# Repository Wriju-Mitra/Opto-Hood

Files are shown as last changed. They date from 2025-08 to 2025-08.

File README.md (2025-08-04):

# Opto-Hood
Low cost system for optogenetically manipulating neurons while simultaneously recording sleep/activity in Drosophila Activity Monitors.
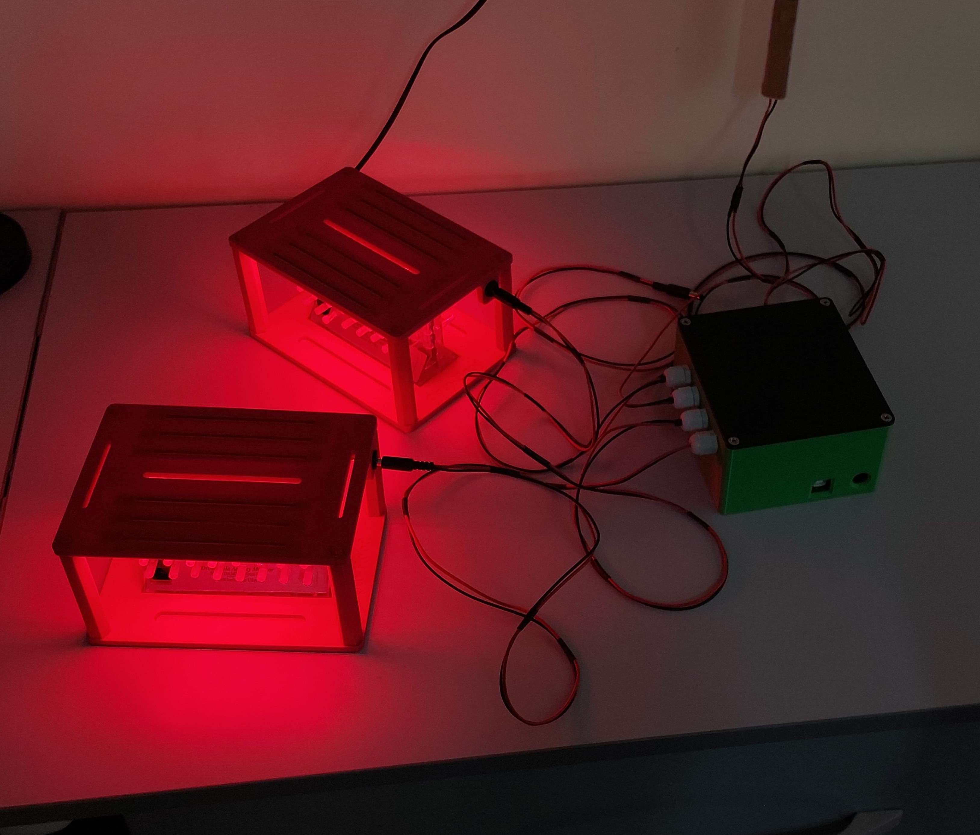
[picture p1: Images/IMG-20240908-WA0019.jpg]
Opto Hood


## Description
The Opto-Hood is a system that allows optogenetic activation(or silencing) of neurons in fruit flies housed in Drosophila Activity Monitors(DAMs). At its heart is an Arduino Uno that controls the duration and frequency of the LEDs that are place over the DAM monitors(like a hood).The system is low cost, and can be built using off-the-shelf electronics. User inputs are acquired through the Arduino IDE hence does not require sophisticated software. Up to four DAMs can be controlled independently by one device.

Detailed info can be found on my [Hackaday page](https://hackaday.io/project/197842-opto-hood)

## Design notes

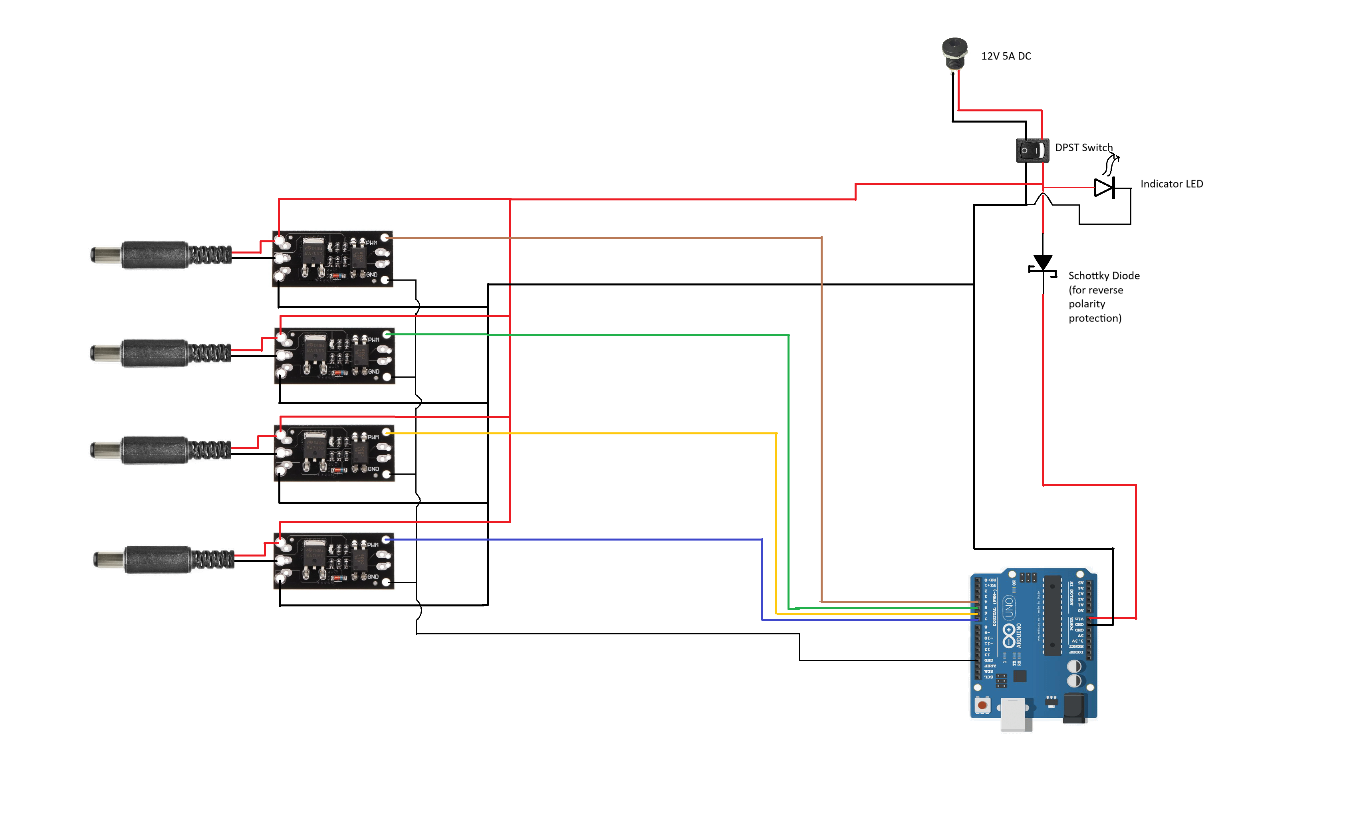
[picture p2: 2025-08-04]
Schematic.png

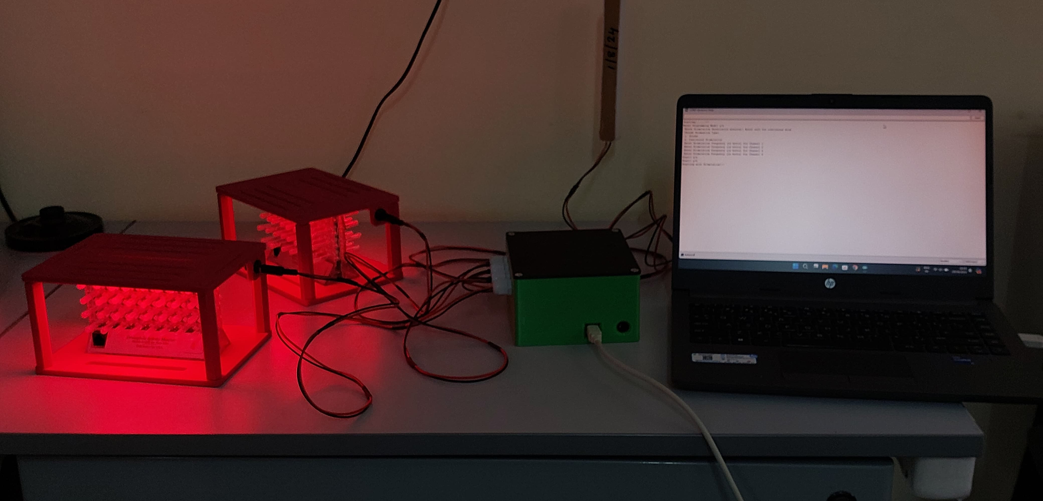
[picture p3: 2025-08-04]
Images/IMG-20240908-WA0015.jpg

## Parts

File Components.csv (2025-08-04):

# | Component Name | No. of units | Comments
1 | Arduino Uno r3 | 1
2 | D4184 Mosfet module | 4
3 | 12V 240 LEDs/meter Red LED strip | 1 | It is preferable to get the 5m strip. Make sure that the LED emits at around 640nm (doesn&apos;t have to be exact, a margin of 30nm on either side is okay)
4 | PG7 cable gland | 4
5 | Barrell Jack 2.2x5.5 Female | 5 | The round type with threads on the outside
6 | Barrell Jack 2.2x5.5 male | 4
7 | 12V 5A power supply | 1
8 | DPST rocker switch | 1
9 | Countersunk Philips Head M3 X 10 mm Bolt | 4
10 | Countersunk Philips Head M3 X 15 mm Bolt | 4
11 | M3 nut | 4
12 | M3 X 6 mm Brass Heat Set Threaded Round Insert | 4
13 | 18AWG insulated wire | 1 | n red and black(10m each) to keep track of wiring
14 | Male to male jumper wires | 7
15 | 1N5822 Schottky diode | 1 | SR560, DR150,etc will also work. A 1N4007 will also work just fine.
16 | Heat shrink 3mm/4mm

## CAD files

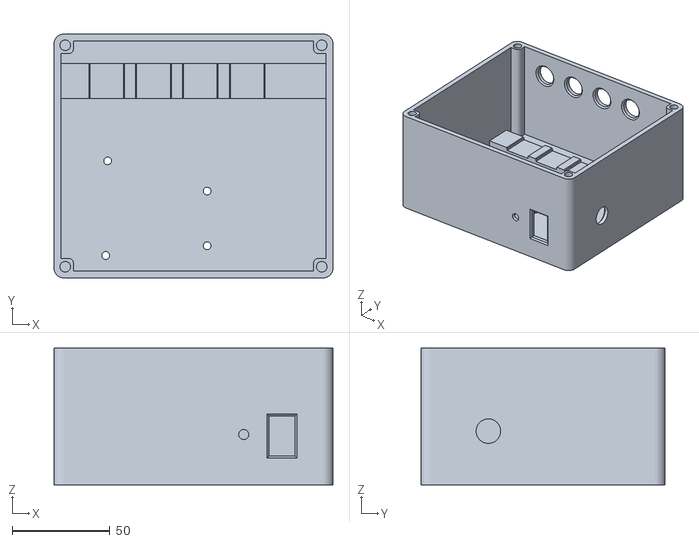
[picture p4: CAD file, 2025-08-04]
Design Files/Opto_Hood_Controller_Box.stl
143.0 x 125.0 x 70.0

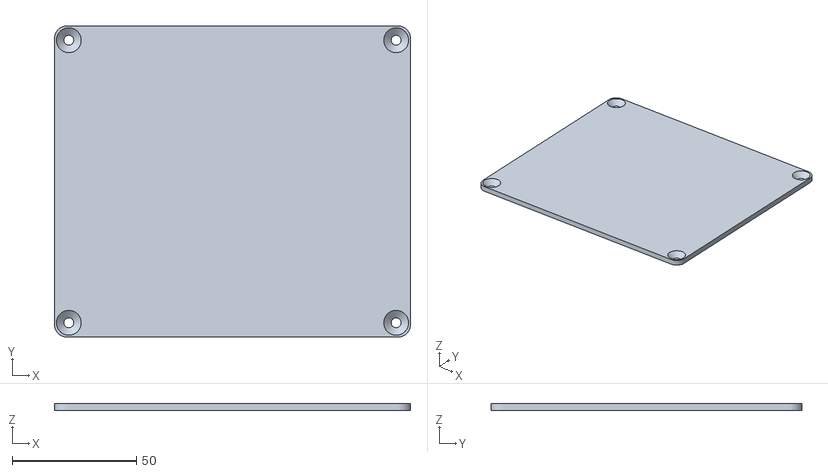
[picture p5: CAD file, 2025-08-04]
Design Files/Opto_Hood_Controller_Box_Lid.stl
143.0 x 125.0 x 3.00

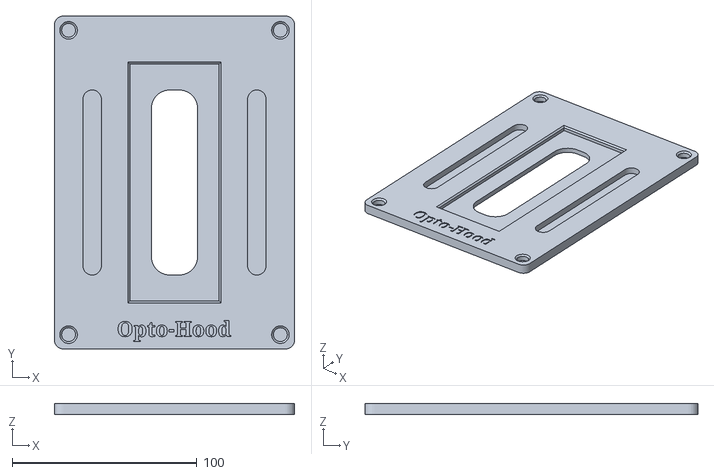
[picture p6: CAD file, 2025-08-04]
Design Files/Opto_Hood_Base.stl
130.0 x 180.0 x 6.00

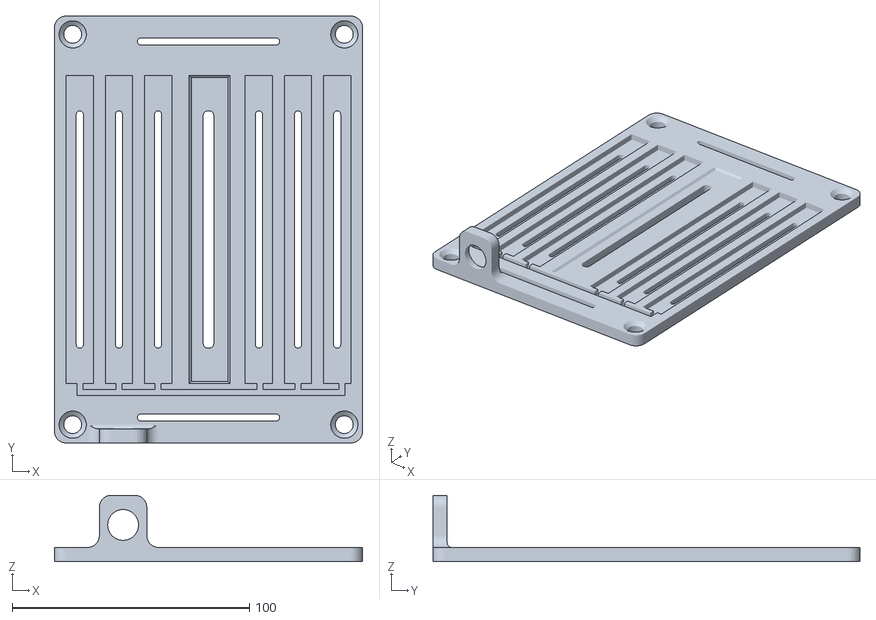
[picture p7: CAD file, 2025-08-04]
Design Files/Opto_Hood_Top.stl
130.0 x 180.0 x 28.0

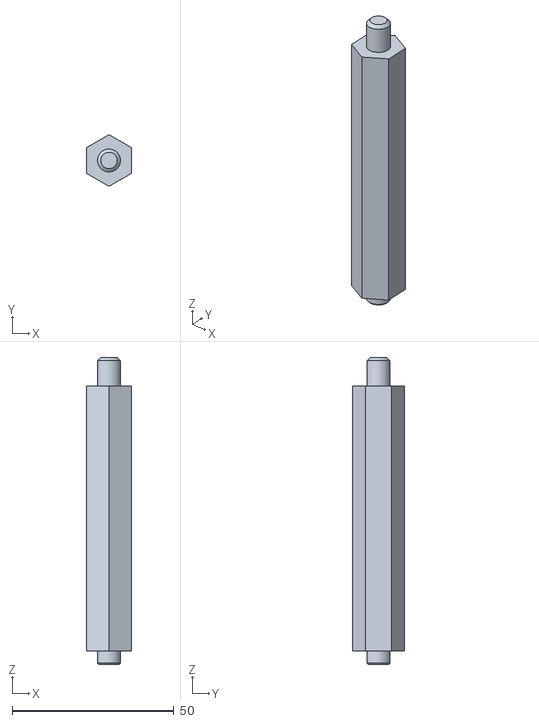
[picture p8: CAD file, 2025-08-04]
Design Files/DAM_Monitor_Opto_top_Post.stl
13.9 x 16.0 x 95.0

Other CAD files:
Design Files/Fusion360/DAM_Monitor_Opto_Top.f3d v3.f3d
Design Files/Fusion360/DAM_Monitor_Opto_Top_Base.f3d v1.f3d
Design Files/Fusion360/DAM_Monitor_Opto_top_Post.f3d v1.f3d
Design Files/Fusion360/Opto_Hood_Controller_Box.f3d v4.f3d
Design Files/Fusion360/Opto_Hood_Controller_Box_Lid.f3d v1.f3d

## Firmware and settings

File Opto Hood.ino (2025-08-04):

/*
 * Opto_Hood
 * 
 * This piece of code controls lights for optogenetic stimulation of flies in DAM monitors for simultaneous sleep/activity recording
 * Four DAM monitors(single beam) are kept in 3d printed "hoods" which have red leds. The arduino controls the power to the hoods through MOSFET/SSRs
 * 
 * General Scheme:                  
 *                           Arduino
 *                              :
 *                              :
 *                              v
 * LED Driver/SMPS ------>MOSFET/Solid State Relay ------> LEDs("Hood")
 * 
 * 
 * The code takes user inputs for time and frequency for each of the channels and then strobes the LEDs accordingly using a non-blocking while loop.
 * Frequencies at higher values might be erroneous as the time taken for each iteration of the loop(calling millis,comparisons,toggling pins) might be too long
 * Generally it is accurate till 50Hz
 * 
 * FOR THOSE WHO WANT MORE:
 * 
 * 
 * 
 * PWM (analogWrite()) won't work as it changes the duty cycle
 * 
 * micros() causes its own problems.First it is not as fast as millis() (reading a register vs. counting overflows). 
 * Also it overflows in little over an hour so extra code is needed to handle such situations.
 * 
 * If high freq is desired then one can use the tone() function (check documentation for reasonable limits) and control all channels at the same rate.
 * This does not allow control over individual channels
 * 
 * It might be possible to use the Timer1 overflow interrupts to control the channels at two different frequencies at fast enough rates.
 * 
 * 
 * Wriju
 * Chouhan Lab
 * TIFR-DBS
 * 25th July 2024
 * 
 * (working)
 * 
 */




const int Ch1 = 7;
const int Ch2 = 6;
const int Ch3 = 5;
const int Ch4 = 4;

String Command;

unsigned long start_time;

unsigned long Ch1_time;
unsigned long Ch2_time;
unsigned long Ch3_time;
unsigned long Ch4_time;
bool Strobe = true;
bool foreverOn = false;
unsigned long Stim_Dur = 0;
unsigned int Stim_Freq = 0;
//unsigned int Ch1_Freq;
//unsigned int Ch2_Freq;
//unsigned int Ch3_Freq;
//unsigned int Ch4_Freq;



void setup() 

{
  pinMode(Ch1, OUTPUT);
  pinMode(Ch2, OUTPUT);
  pinMode(Ch3, OUTPUT);
  pinMode(Ch4, OUTPUT);


  Serial.begin(9600);
  Serial.println("Starting......!!!");
  Serial.setTimeout(60000);
  delay(1000);


  if(Serial)                                                        //Serial.available gave problems
  {
    Serial.println("Enter Programming Mode? y/n");
    while(true)
       {        
        Command = Serial.readStringUntil('\n');
        if(Command.equals("y"))
          break;
        }   

    while(true)
        {
         Serial.println(" Enter Stimulation Duration(in minutes): Enter zero for continuous stim");
      
         Command = Serial.readStringUntil('\n');
         if(Command.toInt()> 0)
        {
          Stim_Dur = Command.toInt();   
          break;
        }
         
        else if(Command.toInt() == 0)
        {
          foreverOn = true;
          break;
        }
         
         else
         
          Serial.println(" Wrong Input! ");
          
        }    


    while(true)
        {
         Serial.println(" Choose Stimuation Type: ");
         Serial.println(" 1. Strobe ");
         Serial.println(" 2. Continuous Stimulation ");
      
         Command = Serial.readStringUntil('\n');
         if(Command.toInt() == 1)  
        {
          Strobe=true;
          while(true)
        {
         Serial.println(" Enter Stimulation Frequency (in hertz) for Channel 1 ");
      
         Command = Serial.readStringUntil('\n');
         if(Command.toInt()>0)  
       {
          //Stim_Freq = Command.toInt();

          Ch1_time = (1000/Command.toInt())/2;      //converting frequency in hertz to time period then deviding by 2 to get half time period
          break;
       }

         else
          Serial.println(" Wrong Input! ");

        }



         while(true)
        {
         Serial.println(" Enter Stimulation Frequency (in hertz) for Channel 2 ");
      
         Command = Serial.readStringUntil('\n');
         if(Command.toInt()>0)  
       {
         // Stim_Freq = Command.toInt();

          Ch2_time = (1000/Command.toInt())/2;  //converting frequency in hertz to time period then deviding by 2 to get half time period
          break;
       }

         else
          Serial.println(" Wrong Input! ");

        }

          while(true)
        {
         Serial.println(" Enter Stimulation Frequency (in hertz) for Channel 3 ");
      
         Command = Serial.readStringUntil('\n');
         if(Command.toInt()>0)  
       {
          //Stim_Freq = Command.toInt();

          Ch3_time = (1000/Command.toInt())/2;      //converting frequency in hertz to time period then deviding by 2 to get half time period
          break;
       }

         else
          Serial.println(" Wrong Input! ");

        }

          while(true)
        {
         Serial.println(" Enter Stimulation Frequency (in hertz) for Channel 4 ");
      
         Command = Serial.readStringUntil('\n');
         if(Command.toInt()>0)  
       {
          //Stim_Freq = Command.toInt();

          Ch4_time = (1000/Command.toInt())/2;     //converting frequency in hertz to time period then deviding by 2 to get half time period
          break;
       }

         else
          Serial.println(" Wrong Input! ");

        }


        break;
        } // end of acquiring channel frequencies

          else if(Command.toInt()== 2)  
       {
          Strobe = false;
          break;
        }

        }
      
         while(true)
        {
         Serial.println("Start? y/n");
      
         Command = Serial.readStringUntil('\n');
        if(Command.equals("y"))
          break;
         
        }
        


     

    
  }// end of acquiring user inputs


  Stimulate();

  
}



void loop() 
{
  // put your main code here, to run repeatedly:

}

void Stimulate()
{
   //Serial.println(Ch1_time);
  // Serial.println(Ch2_time);
   Serial.println("Starting with Stimulation!!!");
   start_time = millis();
   
   unsigned long Ch1_start_time = start_time;                     // start_time for each channel is the half time period
   unsigned long Ch2_start_time = start_time;                     
   unsigned long Ch3_start_time = start_time;
   unsigned long Ch4_start_time = start_time;
  

  
   bool Ch1_State = 0;
   bool Ch2_State = 0;
   bool Ch3_State = 0;
   bool Ch4_State = 0;



   

  

Stim_Dur = Stim_Dur*1000*60;           // convert mins to millisecs
             
if(Strobe)
{
 //Serial.println("Inside Strobe");
 
while((millis() - start_time) < Stim_Dur || foreverOn)          // this loop controls the total duration of Stimulation
  {                                                             //Time_Now is refreshed at each iteration
   unsigned long Time_Now = millis();                           //calling millis is time consuming so the value is stored in one variable.
  
   /*Serial.print(Time_Now);
    Serial.print("          ");
   Serial.print(Ch1_start_time);
    Serial.print("          ");                   //Printing to serial takes too much time so the frequencies would be off. Try not to print in the loop
   Serial.print(Ch1_time);
    Serial.print("          ");
    Serial.print(Ch4_start_time);
    Serial.print("          ");
   Serial.print(Ch4_time);
   Serial.println();
*/
 

      if(Time_Now - Ch1_start_time > Ch1_time)            // if this difference is greater then the state of the switch is toggled
      {
              
       Ch1_State = !Ch1_State;
       digitalWrite(Ch1, Ch1_State);
       digitalWrite(13, Ch1_State);
      
       
       Ch1_start_time = Ch1_start_time + Ch1_time;                         // start_time is refreshed at every state change
      }
    

    
   
      if(Time_Now - Ch2_start_time > Ch2_time)            
      {
              
       Ch2_State = !Ch2_State;
       digitalWrite(Ch2, Ch2_State);
       Ch2_start_time =Ch2_start_time+Ch2_time;                         
      }
  
   
      if(Time_Now - Ch3_start_time > Ch3_time)            
      {
              
       Ch3_State = !Ch3_State;
       digitalWrite(Ch3, Ch3_State);
       Ch3_start_time =Ch3_start_time+Ch3_time;                         

      }



      if(Time_Now - Ch4_start_time > Ch4_time)           
      {
              
       Ch4_State = !Ch4_State;
       digitalWrite(Ch4, Ch4_State);
       Ch4_start_time =Ch4_start_time+Ch4_time;                        
      }


    
  }//end of while

}// end of strobe

else
   while((millis() - start_time) < Stim_Dur || foreverOn)  
   {
    digitalWrite(Ch1, HIGH);
    digitalWrite(Ch2, HIGH);
    digitalWrite(Ch3, HIGH);
    digitalWrite(Ch4, HIGH);
   }


    digitalWrite(Ch1, LOW);
    digitalWrite(Ch2, LOW);
    digitalWrite(Ch3, LOW);
    digitalWrite(Ch4, LOW);


   Serial.println("End of Stimulation!!!");
  
}// end of Stimulate

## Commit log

2025-08-04 Add files via upload
    Contains 3D printable .stl files and Autodesk Fusion360 files
    [DAM_Monitor_Opto_Top.f3d v3.f3d, DAM_Monitor_Opto_Top_Base.f3d v1.f3d, DAM_Monitor_Opto_top_Post.f3d v1.f3d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]
2025-08-04 Add files via upload
    Parts list
    [Components.csv]
